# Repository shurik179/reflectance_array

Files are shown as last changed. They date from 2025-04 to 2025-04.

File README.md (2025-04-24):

# Reflectance array
This repository contains code, hardware design files and more  for a 6-sensor reflectance line array with i2c interface. 
It is work in progress.

Structure of the repository:
- docs: source files for readthedocs documentation 
- hardware: board design files (KiCad8)
- firmware: board firmware (Arduino sketch,using [megatinycore Arduino core](https://github.com/SpenceKonde/megaTinyCore))
- python_lib: library for using the sensor (Micropython/CircuitPython)
- 3d printed: various 3d printed mounts (including a mount for XRP robot)

## Features:
- 6 long-range reflectance sensors 
- built-in MCU (attiny1616) takes care of reading the sensors and computing the calibrated reading 
- i2c interface; supports normal (100k) and fast (400k) speeds
- can be connected using [qwiic/stemma qt](https://www.sparkfun.com/qwiic) connector or standard 0.1" headers (need to be soldered)
- can be calibrated, setting black and white values for each sensor individually. Calibration values are preserved even when the sensor is powered off 
- built-in computation of line position for line following applications; supports white on black and black on white lines 
- built-in I2C pullups (3.3k) on SDA, SCL lines. Can be disabled by cutting open the solder bridge labeled "I2C pullups"
- configurable I2C address
- provided library for use with micropython/circuitpython (Arduino library coming soon)

All of the above is distributed under open source license (MIT). See LICENSE file in this repository for details. 

Detailed description and user guide can be found at https://reflectance-array.readthedocs.io/

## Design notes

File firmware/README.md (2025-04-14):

# Firmware
Firmware is written in Arduino IDE, using [megaTinyCore](https://github.com/SpenceKonde/megaTinyCore) core. Choose attiny 1616 board, 10 Mhz. 

To upload it to the board, I used Adafruit's [UPDI fiend](https://www.adafruit.com/product/5879); I soldered pogo pins to it to connect with test points on the sensor.

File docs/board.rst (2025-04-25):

**********************
Hardware details
**********************

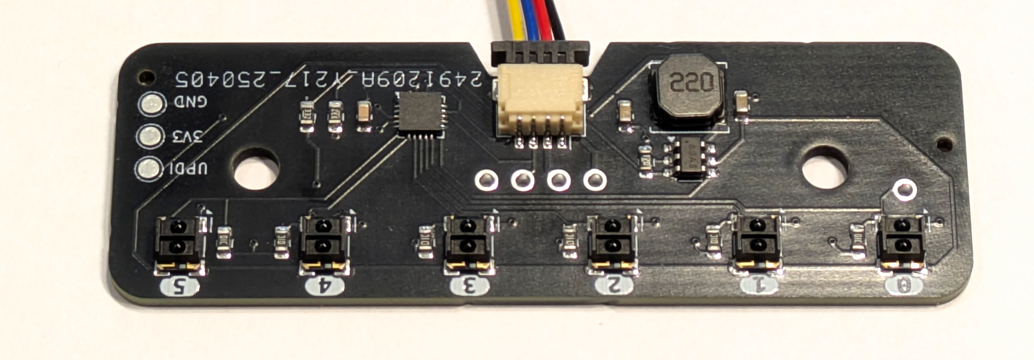
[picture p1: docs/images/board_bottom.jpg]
board bottom view


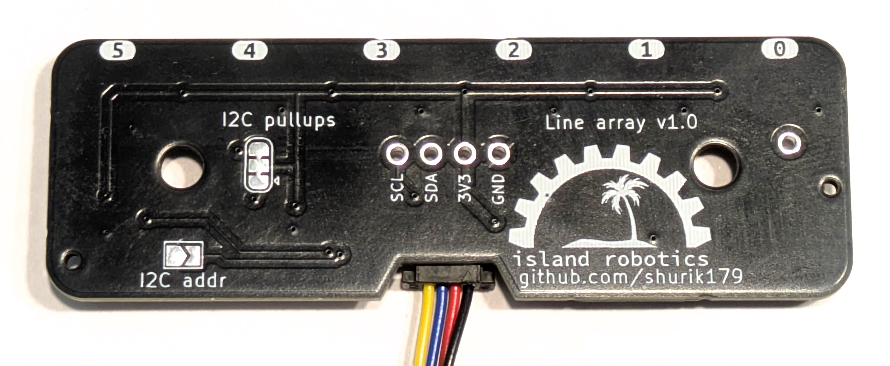
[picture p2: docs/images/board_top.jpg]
board top view


The photos above show the reflectance array sensor board. It contains the following elements:

* Six individual reflectance sensors. We use `ITR1502 <https://www.everlight.com.cn/wp-content/plugins/ItemRelationship/product_files/pdf/ITR1502SR40A-TR8.pdf>`__ 
  sensors, which have much longer range than typical reflectance sensor (4mm vs 1mm). The sensors are spaced 10mm apart
* Constant current LED driver; this makes the sensor much more efficient as no power is wasted on resistors
* An attiny 1616 MCU 
* A `qwiic/stemma qt <https://www.sparkfun.com/qwiic>`__ connector and holes for soldering an 0.1" headers
* Power requirements: the board uses about 50 mA at 3.3v. It is possible to turn off the LEDs in software 
  to save power. 

Board dimensions are shown below. 

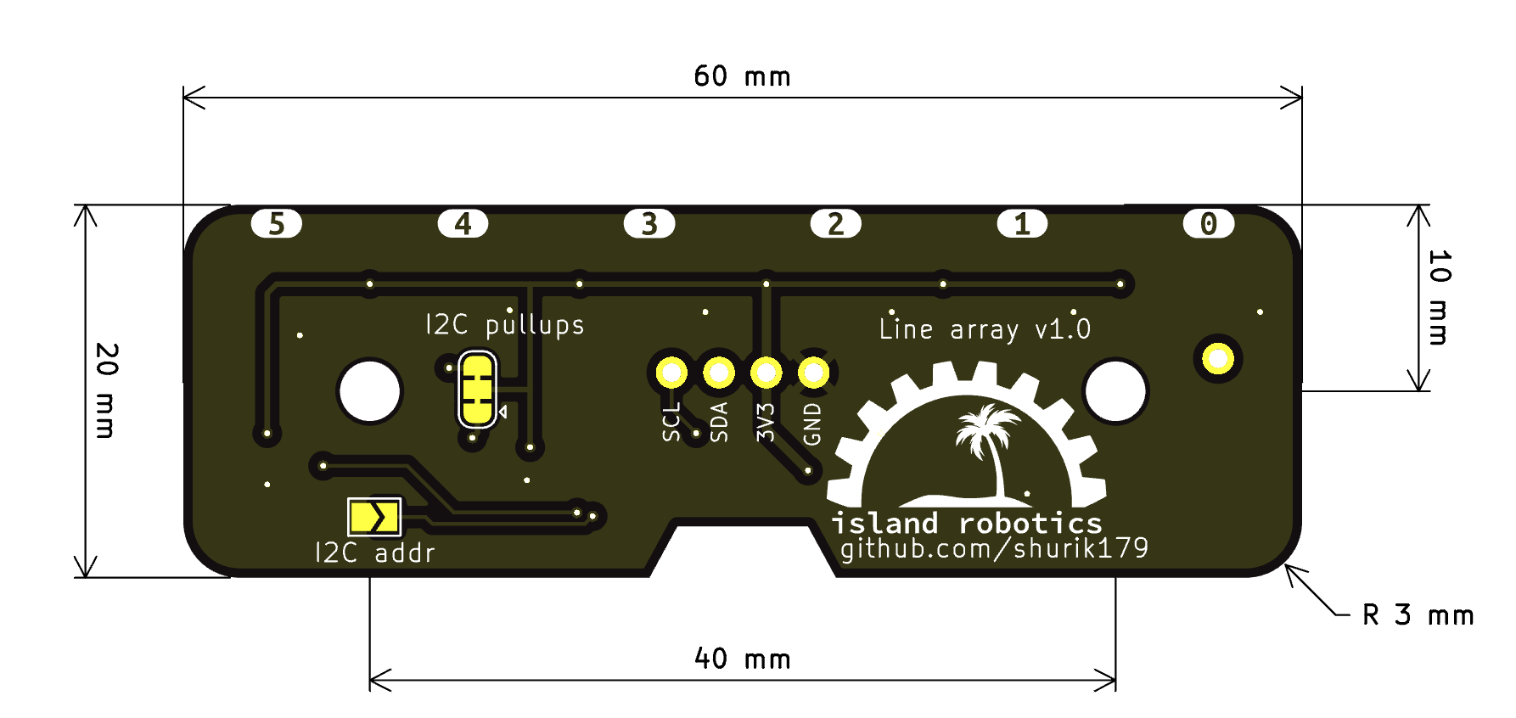
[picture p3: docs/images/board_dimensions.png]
board dimensions


To connect the sensor to your microcontroller, use a qwiic cable (available from `Adafruit <https://www.adafruit.com/product/4210>`__ 
or `Sparkfun <https://www.sparkfun.com/flexible-qwiic-cable-100mm.html>`__ ) 
to connect it to the i2c connector of the MCU. 

By default, the sensor uses i2c address 0x11. However, you can change that: if you close the solder bridge 
labeled "I2C addr", the sensor will use i2c address  0x12. This allows one to use two such sensors on the same i2c bus.

The sensor contains 3.3k pullup resistors on SCL, SDA lines. If for some reason you do not need them (e.g., 
the host MCU already provides pullups), you can disable them by cutting the two traces of the "I2C pullups" 
solder bridge using a sharp knife. 

To mount the sensor to your robot, you can use the mounting holes; they  have 3.2mm diameter 
and are intended to be used with M3 screws. Alternatively, you can make a 3d-printed snap mount - one such snap 
mount for XPR robot can be found in 3d printed folder in |github|.  The sensor should be mounted so that the 
distance from the bottom of the PCB to ground is about 6 mm.

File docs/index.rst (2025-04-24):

####################################
Reflectance Array with I2C interface
####################################

board bottom view

This document describes the reflectance array sensor created by `shurik179 <https://github.com/shurik179>`__. 
It is intended for use with small robots for tasks such as line following, sumo robots, and more.  All software and hardware 
files are available under an open source license from the project |github|; 
you can also buy a completed sensor from my Tindie store. 

Below are the key features of this sensor.

* **Dimensions:** 20x60 mm
* includes **6 individual reflectance sensors** (long range - 
  optimal distance to measured object is 4mm)
* has **i2c interface**, which supports normal (100k) and fast (400k) speeds
* contains an MCU (attiny 1616) which takes care of reading individual sensor input,  applying calibrations, and computing line position for line following tasks
* provides **qwiic/stemma qt connector** as well as standard 0.1" header connector (requires soldering)
* can be turned off to save batteries
* provided micropython/Circuit Python library (Arduino library will be added shortly)

.. toctree::
    :caption: Table of Contents
    :maxdepth: 1

    board
    software_installation
    library

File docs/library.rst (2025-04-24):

.. _library:
**************************
Python Library Reference
**************************

In this chapter, we give full list of all commands provided by refelectance 
array micropython/Circuit Python library.

This document describes version 1.0 of the library. It assumes that you 
had already created a  LineArray object; all methods below are methods 
of this object. Sensor index s ranges between 0--5; 0 is the rightmost sensor, and 5, the leftmost.

Basic commands
==============

.. function:: start()
.. function:: stop() 

    Starting and stopping the sensor. By default, the sensor is active. To save battery, 
    you can stop it by using `stop()`; this turns off the power to IR LEDs inside reflectance 
    sensors.  Note that you can still read the reflectance sensor values even when the LEDs are off; 
    this can be useful for detecting ambient light changes.

.. function:: fw_version()

    Returns firmware version as a string, e.g. `1.3`

.. function:: raw(s)

   Returns raw reading of  s-th reflection sensor (0-1023). The darker the surface, 
   the lower the value. Typical value on a white sheet of paper is around 950, 
   and on black plastic, around 120. 

Calibration
===========
You can calibrate the sensor, recording  values for black and white; these values 
will be used for computing calibrated readings and for deciding when the sensor 
is on black/white (see below). 

 The calibration values are saved in EEPROM, which means that they are preserved  
 even when you turn off the  power to the sensor; they  will be loaded on next power-up. 

.. function:: start_cal()
.. function:: end_cal()

   Starts and stops calibration. In between these commands, it is expected that 
   you move the robot so that each sensor sees both white and black. The lowest 
   recorded value will be saved as black calibration, and the highest, as white 
   calibration; these are saved individaully per sensor.

.. function:: get_cal_black(s)
.. function:: get_cal_white(s)

   Returns the value of black (respectively, white) calibration for sensor s. 
   This is rarely needed - mostly to verify that calibration was successful 
   in cases when your sensor behaves unexpectedly. 

Calibrated readings
===================
.. function:: calibrated(s)

   This function assumes that you had already calibrated your sensor. It returns 
   calibrated value. For example, if calibration values were 300 (black) and 800 (white)
   then raw reading of 300 or less  will give calibrated reading 0, raw reading of 800 
   or above will give calibrated reading of 1023, and all values in between will be 
   rescaled linearly - e.g., raw reading of 550 (which is exactly the midpoint between 300 and 800)
   will give calibrated reading of 512. 

Digital readings
================  
In many cases you only need to know if the sensor is on black/white and not interested in exact reading. 
In these cases, it is much faster to use the functions below. As before, you should calibrate 
your sensor before using these functiosn. 

.. function:: on_black(s)
.. function:: on_white(s)

   Returns True if sensor s is on black (respectively, white) and False otherwise. 
   The cutoff between white and black is defined to be the  midpoint between black 
   and white calibration values. 

.. function:: all_black()
.. function:: all_white()

   Returns True if all sensors are on black (respectively, white) and False otherwise. 

Line position 
=============

For line following tasks, you can use the functions below. They work best with line widths of 1/2-3/4" 
(12-20mm). 

.. function:: set_linemode(mode)

   Sets the mode for line position function. There are two possible modes: 
   LINEMODE_WHITEONBLACK - for tracking white line on black background 
   LINEMODE_BLACKONWHITE - for black line on white background

.. function:: line_pos()

   Returns the position of the line under the robot. The return  value ranges 0-100; 
   0 means that the line is all the way to the right and 100, all the way to the left. 
   If no sensor sees the line, the function will still return a value, which is unpredictable.

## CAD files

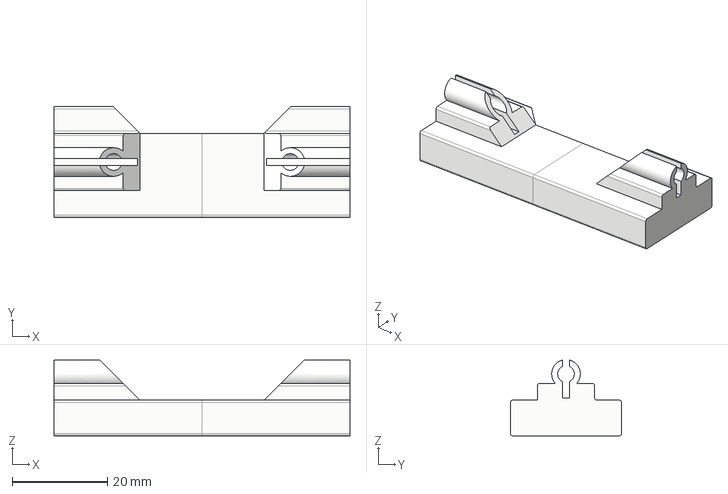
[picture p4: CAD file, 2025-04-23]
3d-printed/Reflectance array mount for XRP.step
62.0 x 23.3 x 15.9 mm

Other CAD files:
3d-printed/Refelctance array mount for XRP.f3d

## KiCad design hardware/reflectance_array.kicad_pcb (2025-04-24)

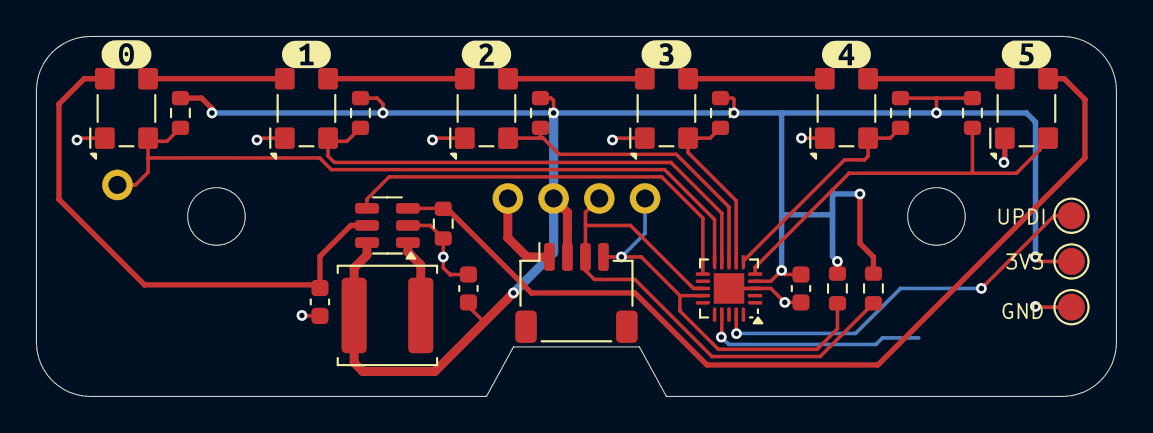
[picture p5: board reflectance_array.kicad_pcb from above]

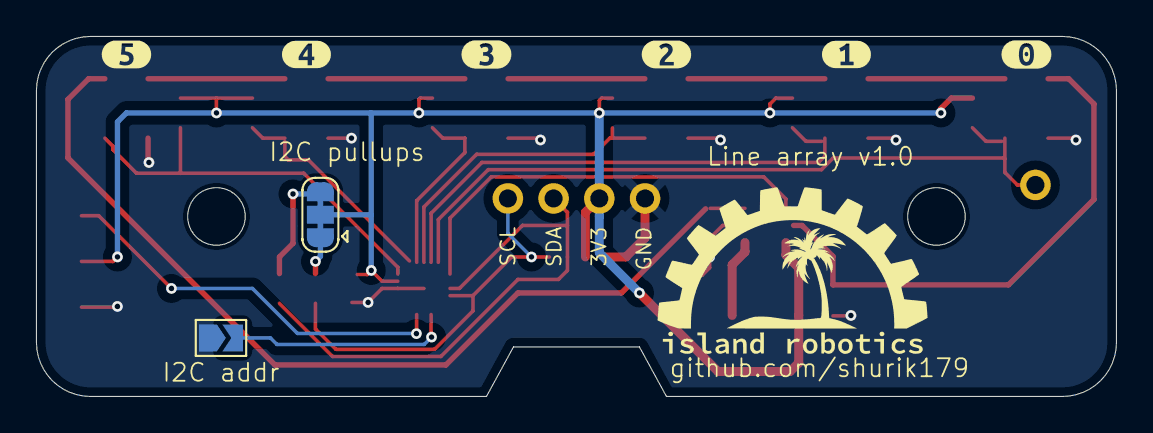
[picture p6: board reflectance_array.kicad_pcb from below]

Board: 2 copper layers, 60.0 x 20.0 mm, 41 parts (9 on the bottom side), 21 nets.

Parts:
C1, C2: 1uF; C_0603_1608Metric
C3: 100nF; C_0603_1608Metric
J1: Conn_01x01_Pin; connector-1p-generic-nosilk
J2: Conn_01x04_Pin; JST_SH_SM04B-SRSS-TB_1x04-1MP_P1.00mm_Horizontal
J3: Conn_01x04_Pin; connector-4p-generic-nosilk
JP1: SolderJumper_2_Open; SolderJumper-2_P1.3mm_Open_TrianglePad1.0x1.5mm
JP2: SolderJumper_3_Bridged123; SolderJumper-3_P1.3mm_Bridged123_RoundedPad1.0x1.5mm
L1: 22uH; L_Sunlord_SWPA5020S
R1: 12; R_0603_1608Metric
R2, R3, R4, R5, R6, R8: 10K; R_0603_1608Metric
R7, R9: 3.3K; R_0603_1608Metric
TP1, TP2, TP3: TestPoint; TestPoint_Pad_D1.5mm
U1: AP3019A; TSOT-23-6
U2, U3, U5, U6, U7, U8: ITR1502SR40A; Everlight_ITR1502SR40A
U4: ATtiny1616-M; VQFN-20-1EP_3x3mm_P0.4mm_EP1.7x1.7mm
kibuzzard-67E182C9: G***; kibuzzard-67E182C9
kibuzzard-67E182D6: G***; kibuzzard-67E182D6
kibuzzard-67E182E1: G***; kibuzzard-67E182E1
kibuzzard-67E182EE: G***; kibuzzard-67E182EE
kibuzzard-67E182F6: G***; kibuzzard-67E182F6
kibuzzard-67E1830C: G***; kibuzzard-67E1830C
kibuzzard-67E1831D: G***; kibuzzard-67E1831D
kibuzzard-67E1832E: G***; kibuzzard-67E1832E
kibuzzard-67E18323: G***; kibuzzard-67E18323
kibuzzard-67E18328: G***; kibuzzard-67E18328
kibuzzard-67E18337: G***; kibuzzard-67E18337
kibuzzard-67E18343: G***; kibuzzard-67E18343

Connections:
+3V3: C1.1, C3.1, J2.2, J3.2, JP2.1 (A), JP2.2 (C), JP2.3 (B), L1.1, R2.1, R3.1, R4.1, R5.1, R6.1, R7.1, R8.1, R9.1, TP2.1, U1.6 (VIN), U4.4 (VCC)
/FB: R1.1, U1.3 (FB), U8.3 (K)
/I2C_ADDR: JP1.2 (B), U4.17 (PC2)
/LED_ENABLE: U1.4 (CTRL), U4.11 (PB3)
/S0: J1.1, R2.2, U2.2, U4.10 (PB4)
/S1: R3.2, U3.2, U4.9 (PB5)
/S2: R4.2, U4.8 (PA7), U5.2
/S3: R5.2, U4.7 (PA6), U6.2
/S4: R6.2, U4.6 (PA5), U7.2
/S5: R8.2, U4.5 (PA4), U8.2
/SCL: J2.4, J3.4, R7.2, U4.14 (PB0)
/SDA: J2.3, J3.3, R9.2, U4.13 (PB1)
/UPDI: TP1.1, U4.19 (~RESET/PA0)
/VCC_LED: C2.1, U1.5 (VOUT), U2.4 (A)
GNDREF: C1.2, C2.2, C3.2, J2.1, J3.1, JP1.1 (A), R1.2, TP3.1, U1.2 (GND), U2.1, U3.1, U4.3 (GND), U4.21 (GND), U5.1, U6.1, U7.1, U8.1
unnamed: L1.2, U1.1 (SW)
unnamed: U2.3 (K), U3.4 (A)
unnamed: U3.3 (K), U5.4 (A)
unnamed: U5.3 (K), U6.4 (A)
unnamed: U6.3 (K), U7.4 (A)
unnamed: U7.3 (K), U8.4 (A)

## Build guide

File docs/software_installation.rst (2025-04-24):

**********************
Software installation
**********************

The sensor comes with a micropython/circuit python library, which can be found in the |github|. 
To use it, please download the latest release archive file from https://github.com/shurik179/reflectance_array/releases. 
Extract the archive file to a convenient location and find inside folder 'python_lib', which contains the library 
and example code. Upload the file 'lib/linearray.py' to '/lib' folder on your microcontroller (the same file can 
be used both for micropython and Circuit Python).

For Circuit Python, you also need 'adafruit_bus_device' library; most boards with CircuitPython 
already include that library - see info at the 
library `github repository  <https://github.com/adafruit/Adafruit_CircuitPython_BusDevice>`__

The following python code gives the simplest example of using this library.

Micropython (make sure to use correct i2c pin numbers)

.. code-block:: python

    import time
    from linearray import *
    from machine import Pin, I2C
    i2c = I2C(0, sda=Pin(4), scl=Pin(5), freq=400000)
    sensor=LineArray(i2c)
    print("Firmware version: {}".format(sensor.fw_version()))
    time.sleep(2)
    sensor.start()
    while True:
        for s in range(6):
            value = sensor.raw(s)
            # formatted to take 4 characters, for better alignment
            print(f'{value:4}', end=' ')
        print('') #just to end the line
        time.sleep(0.3)

Circuit Python (you may need to replace 'board.I2C()' by 'board.STEMMA_I2C()', see https://learn.adafruit.com/circuitpython-essentials/circuitpython-i2c)

.. code-block:: python

    import time
    from linearray import *
    import board 
    i2c = board.I2C()
    sensor=LineArray(i2c)
    print("Firmware version: {}".format(sensor.fw_version()))
    time.sleep(2)
    sensor.start()
    while True:
        for s in range(6):
            value = sensor.raw(s)
            # formatted to take 4 characters, for better alignment
            print(f'{value:4}', end=' ')
        print('') #just to end the line
        time.sleep(0.3)

The folder 'Examples' contains several code examples:

* basic_test.py: the basic example - same code as given above
* calibration.py: example of sensor calibration 
* digital.py: when you only need to know if a given sensor is on white/black 
* line_pos.py: getting the position of the line under your robot, for line following 

For a full list of all available methods provided by this library, see :ref:`Python Library <library>`.

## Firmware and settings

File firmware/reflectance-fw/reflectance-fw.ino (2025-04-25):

// SPDX-FileCopyrightText: Copyright 2025 Alexander Kirillov <shurik179@gmail.com>
// SPDX-License-Identifier: MIT
// partly based on https://github.com/SpenceKonde/megaTinyCore/blob/master/megaavr/libraries/Wire/examples/register_model/register_model.ino

#include <Wire.h>
#include <EEPROM.h>

//firmware version 
#define FW_MINOR 0
#define FW_MAJOR 1
#define PIN_ENABLE PIN_PB3
#define PIN_ADDR PIN_PC2 //for changing I2C address

#define NUM_SENSORS 6
#define NUM_REGISTERS 60 //size of register bank, in bytes
#define SLAVE_ADDRESS 0x11
#define MODE_OFF 0
#define MODE_ON 1
#define MODE_CAL 2
#define MODE_CAL_END 3
#define LINEMODE_BLACKONWHITE 0
#define LINEMODE_WHITEONBLACK 1 
volatile uint8_t DevRegister[NUM_REGISTERS]; //register bank
volatile uint8_t WirePointer = 0;
volatile uint8_t ModeChange = 0; //to signal that mode had changed
uint8_t mode = MODE_ON;

//register definitions
#define REG_WHOAMI     0
#define REG_MODE       1
#define REG_LINE_MODE  2
#define REG_FW_MINOR   3
#define REG_FW_MAJOR   4
#define REG_STATUS     5 //for debugging
#define REG_SENSOR_RAW 6 //start of raw readings block. 
                         //each sensor is recorded as two bytes; e.g. raw reading of sensro 0 is 
                         // at registers 6 (low byte) and 7(high byte) 
#define REG_SENSOR_CAL 18 //start of calibrated readings block. 
                         //each sensor is recorded as two bytes; e.g. calibrated reading of sensor 0 is 
                         // at registers 18 (low byte) and 19(high byte) 
#define REG_SENSOR_DIGITAL 30 // byte containing sensor readings in digital (0/1) form, 1 bit for sensor
                              // least significant bit is sensor 0                          
#define REG_LINE_POS 31 //line position as uint8_t, ranges 0-100                               
#define REG_CALIBRATIONS 32 //start of calibration data, 4 bytes per sensor: black low byte, black high, white low, white high


uint8_t SensorPins[NUM_SENSORS] = { PIN_PB4, PIN_PB5, PIN_PA7, PIN_PA6, PIN_PA5, PIN_PA4 };
uint16_t BlackCalibration[NUM_SENSORS] = {120,120,120,120,120,120};
uint16_t WhiteCalibration[NUM_SENSORS] = {980,980,980, 980, 980,980};

uint8_t s; // temporary, sensor index





void setup() {
    pinMode(PIN_ADDR, INPUT_PULLUP);
    pinMode(PIN_ENABLE, OUTPUT);
    digitalWrite(PIN_ENABLE, HIGH);
    if (digitalRead(PIN_ADDR)) { //if high, use default address
        Wire.begin(SLAVE_ADDRESS);       
    } else { //solder bridge was closed - use next 
        Wire.begin(SLAVE_ADDRESS+1);             
    }
    Wire.onReceive(receiveHandler);
    Wire.onRequest(requestHandler);
    DevRegister[REG_WHOAMI] = SLAVE_ADDRESS;
    DevRegister[REG_FW_MINOR] = FW_MINOR;
    DevRegister[REG_FW_MAJOR] = FW_MAJOR;
    DevRegister[REG_MODE] = MODE_ON;
    DevRegister[REG_LINE_MODE] = LINEMODE_BLACKONWHITE;
    //get calibration data from eeprom
    read_calibration();
}

void loop() {
    //check if the mode had been changed; if so, enable/disable the sensors
    if (ModeChange) {
        ModeChange = 0;
        mode = DevRegister[REG_MODE];
        if (mode == MODE_OFF) {
            digitalWrite(PIN_ENABLE, LOW);
        } else {
            digitalWrite(PIN_ENABLE, HIGH);
        }
        if (mode == MODE_CAL) { //starting calibration
            //reset calibrartion data 
            for (s =0; s<NUM_SENSORS; s++){
                BlackCalibration[s]=1023;
                WhiteCalibration[s]=0;
            }
        } else if (mode == MODE_CAL_END) { //ending calibration
            //save calibration data to eeprom  
            save_calibration();
            //automatically switch to run mode 
            DevRegister[REG_MODE] = MODE_ON;
            mode = MODE_ON;
        }
    }
    //if (mode == MODE_OFF) return; //no need to measure anything 
    //otherwise, get sensor values; also compute the average, for line position 
    uint32_t line_pos, weighted_sum = 0;
    uint16_t total_weight = 0;
    uint16_t r;
    for (s=0; s<NUM_SENSORS; s++){
        if (mode == MODE_CAL) {update_calibration(s);}
        else {
            r = update_value(s); //returns calibrated value 
            if (DevRegister[REG_LINE_MODE] == LINEMODE_BLACKONWHITE) {r=1023-r;}
            //computing the weighted average of sensor indexes, using reading as weight
            //will be used for line position
            // if sensor is close to black, let's count it as black  
            
            if (r>=150) {
                r -=150;
            } else {
                r = 0;
            }
            //else if (r>750) {r=1023;}
            weighted_sum += s* r;
            total_weight += r; 
        }
    }
    //now, get the line position 
    if (total_weight) { //just in case, to make sure we are not dividing by 0
        line_pos = (weighted_sum*20)/total_weight; //ranges between 0 - (NUM_SENSORS-1)*20, i.e. 0-100
        DevRegister[REG_LINE_POS] = (uint8_t)line_pos;
    }
}

void receiveHandler(int numbytes) {
    Wire.getBytesRead(); // reset count of bytes read. We don't do anything with it here, but a write is going to reset it to a new value.
    WirePointer = Wire.read(); 
    numbytes--; // we just read a byte, so we should decrement this.
    while (numbytes > 0) { // If numbytes was more than 1, we'll execute the below loop to write to the "registers".
        //the only writable registers are REG_MODE, REG_LINE_MODE, attempts to write to other registers will be ignored
        if  ((WirePointer == REG_MODE) || (WirePointer == REG_LINE_MODE)) {
            DevRegister[WirePointer] = Wire.read();
            ModeChange = 1;
        } else {
            //read byte and discard 
            Wire.read();
        }
        WirePointer++;          // increment the pointer.
        numbytes--;             // decrement remaining bytes.
    }
}


void requestHandler() {
    uint8_t i;
    // We will start reading from the pointer
    i = WirePointer;
    while (i< NUM_REGISTERS) {
        Wire.write(DevRegister[i]);
        i++;
        // "write" the whole array - but the master might only want one byte.
        // The slave doesn't know how much data the master will want yet.
        // and won't know until it's gotten all that it wants and has generated a stop condition.
    }
  
}

//Updates readings of sensor index s (normal mode)
//returns the reading as uint16_t
uint16_t  update_value(uint8_t s){
    uint16_t reading; 
    int32_t calReading;
    reading = 1023 - analogRead(SensorPins[s]); // so that black corresponds to 0, and white, to 1023
    DevRegister[REG_SENSOR_RAW + 2*s] = (uint8_t) reading; //low byte
    DevRegister[REG_SENSOR_RAW + 2*s+1] = (uint8_t)(reading>>8);     //high byte
    //now, do the calibrated ones
    
    calReading = 1023*((int32_t)reading - BlackCalibration[s]);
    calReading /= WhiteCalibration[s]- BlackCalibration[s];
    if (calReading < 0) calReading = 0;
    if (calReading > 1023) calReading = 1023;
    DevRegister[REG_SENSOR_CAL + 2*s  ] = (uint8_t) calReading; //low byte
    DevRegister[REG_SENSOR_CAL + 2*s+1] = (uint8_t) (calReading>>8);     //high byte
    //do the digital ones 
    if (calReading >= 512){
        //sensor s is white: set s-th bit
        DevRegister[REG_SENSOR_DIGITAL] |= (1<<s); 
    } else {
        //sensor s is black: unset s-th bit  
        DevRegister[REG_SENSOR_DIGITAL] &= ~(1<<s);             
    }
    return(calReading);
}

void update_calibration(uint8_t s){
    uint16_t reading; 
    reading = 1023 - analogRead(SensorPins[s]); // so that black corresponds to 0, and white, to 1023
    if (reading < BlackCalibration[s]) {
        BlackCalibration[s] = reading;
    }
    if (reading > WhiteCalibration[s]) {
        WhiteCalibration[s] = reading;
    }
}



// saves calibration data to eeprom
void save_calibration(){
    for (s = 0; s<NUM_SENSORS; s++){
        // each value takes 2 bytes, so 4 bytes per sensor: 2 for black value, 2 for white
        EEPROM.put(4*s,  BlackCalibration[s]);
        EEPROM.put(4*s+2,  WhiteCalibration[s]);
        //now, save to register
        DevRegister[REG_CALIBRATIONS+4*s]  = (uint8_t)BlackCalibration[s];
        DevRegister[REG_CALIBRATIONS+4*s+1]= (uint8_t)(BlackCalibration[s]>>8);
        DevRegister[REG_CALIBRATIONS+4*s+2]= (uint8_t)WhiteCalibration[s];
        DevRegister[REG_CALIBRATIONS+4*s+3]= (uint8_t)(WhiteCalibration[s]>>8);
    }
}

//gets calibration data from eeprom
void read_calibration (){
    uint16_t white, black;
    for (s = 0; s<NUM_SENSORS; s++){
        // each value takes 2 bytes, so 4 bytes per sensor: 2 for black value, 2 for white
        EEPROM.get(4*s,  black);
        EEPROM.get(4*s+2,  white);
        if ( (white > 0 ) && (white <= 1023) ) { //basic sanity check, to make sure eeprom has valid values
            BlackCalibration[s] = black;
            WhiteCalibration[s] = white;
        }
        //now, save to register
        DevRegister[REG_CALIBRATIONS+4*s]  = (uint8_t)BlackCalibration[s];
        DevRegister[REG_CALIBRATIONS+4*s+1]= (uint8_t)(BlackCalibration[s]>>8);
        DevRegister[REG_CALIBRATIONS+4*s+2]= (uint8_t)WhiteCalibration[s];
        DevRegister[REG_CALIBRATIONS+4*s+3]= (uint8_t)(WhiteCalibration[s]>>8);
    }
}

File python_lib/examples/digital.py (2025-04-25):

# SPDX-FileCopyrightText: Copyright 2025 Alexander Kirillov <shurik179@gmail.com>
# SPDX-License-Identifier: MIT
# This file is part of reflectance sensor array sotware library: https://github.com/shurik179/reflectance_array
# 
# Basic sensor digital test: checking if a given sensor is on black/on white
# Make sure you have run calibration before using this test 
# 

import time
from linearray import *

# YOU MUST UNCOMMENT ONE OF THE OPTIONS BELOW

# FOR MicroPython: uncomment two lines below
from machine import Pin, I2C
i2c = I2C(0, sda=Pin(4), scl=Pin(5), freq=400000)
# end of micropython-specific block 

# FOR CircuitPython: Uncomment below. For i2c bus, you can use board.I2C() or board.STEMMA_I2C()
# import board 
# i2c = board.I2C()
# end of circuitpython-specific block 

# Common to both MP and CP:
# first argument is i2c bus
# second argument (optional) is I2C address; choices are 0x11 (default) or 0x12
# sensor = LineArray(i2c, 0x12)

sensor=LineArray(i2c)



print("Firmware version: {}".format(sensor.fw_version()))
time.sleep(2)
sensor.start()
#print out current calibration values (optional)
print("current calibration")
print("Black White")
for s in range(6):
    black = sensor.get_cal_black(s)
    white = sensor.get_cal_white(s)
    print(f'{black:5} {white:5}')
time.sleep(3)
while True:
    for s in range(6):
        if (sensor.on_white(s)):
           print("1 ", end=' ')
        else:
            print("0 ", end=' ')
    if (sensor.all_white()):
        message = " all on white"
    elif (sensor.all_black()):
        message = " all on black "
    else:
        message = ' '
    print(message) #just to end the line
    time.sleep(0.3)

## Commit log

2025-03-24 first draft version
    [reflectance_array.kicad_pcb, reflectance_array.kicad_sch]
2025-03-24 version 0.1
    [reflectance_array.kicad_pcb, reflectance_array.kicad_sch]
2025-04-05 version 1.0
    [reflectance_array.kicad_pcb, reflectance_array.kicad_sch]
2025-04-23 adding micropython library
    [Refelctance array mount for XRP.f3d, Reflectance array mount for XRP.step, reflectance_array_yozh.kicad_sch]
2025-04-24 docs update
    [reflectance_array.kicad_pcb]
2025-04-25 fixing stupid bug in digital reading part of firmware
    [digital.py, reflectance-fw.ino]
